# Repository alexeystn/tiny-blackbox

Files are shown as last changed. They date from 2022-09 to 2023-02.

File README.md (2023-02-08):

# Tiny Blackbox
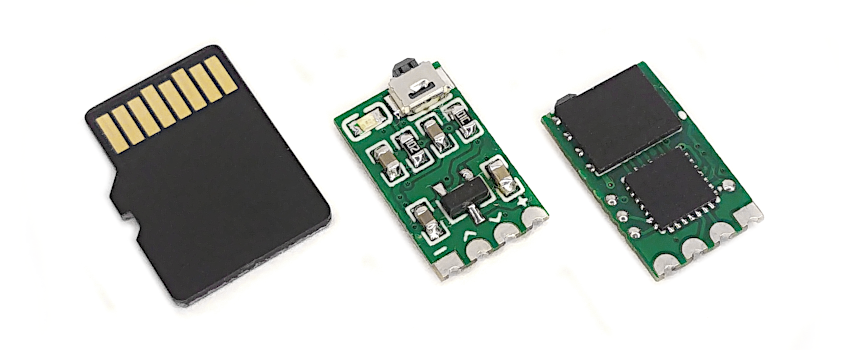
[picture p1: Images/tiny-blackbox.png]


Tiny Blackbox - open source ultra-light external logger for micro drones.<br>

* Size: 8 x 13 mm
* Weight: 0.32 g
* Logging rate: up to 8 kHz 
* Data rate: 1.5 Mbit/s
* Current consumption: < 30 mA
* Flash memory: 16 MB, W25Q128JVPIQ <br>
 &gt; 3 min at 4 kHz, full log <br>
 &gt; 45 min at 1 kHz, gyro-only log (all other fields disabled)
* MCU: STM32G031G8U6

For previous version with F042 chip go to [this page](https://github.com/alexeystn/tiny-blackbox/tree/stm32f042)

## Setup
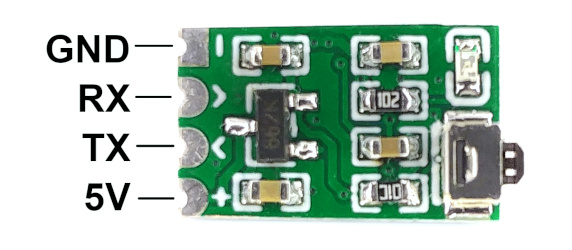
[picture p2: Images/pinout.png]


1) Connect the device to any free UART port on your flight controller (RX->TX, TX->RX).<br>
Signal wires must be tightly twisted to prevent interference.
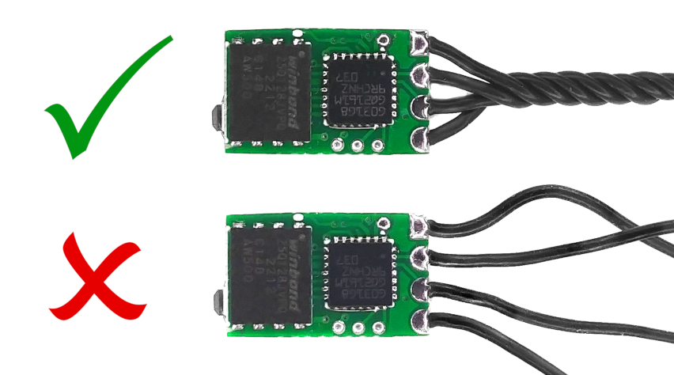
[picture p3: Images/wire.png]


2) Setup blackbox in Betaflight Configurator:
* Ports tab: Peripherals -> Blackbox logging, speed 1500000.
* Modes tab: Blackbox -> assign to any available AUX switch.
* Blackbox tab: Logging device -> Serial Port.
<details>
<summary><b>Screenshots</b></summary>
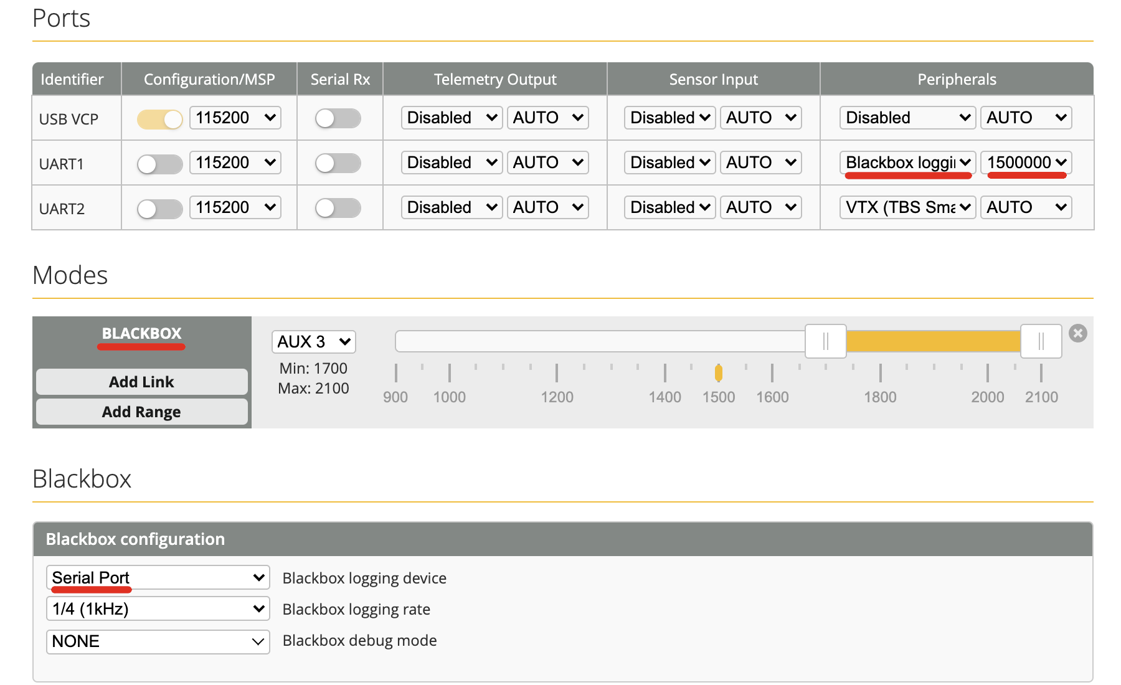
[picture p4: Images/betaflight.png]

</details>
<b>Warning!</b> Betaflight 4.3.1 has a bug in USB code, so logs might be corrupted when downloaded to PC. <br>
Please use Tiny Blackbox with Betaflight 4.4.x, 4.3.0, 4.3.2+ or 4.2.x.<br>
<br>

<b>Notice:</b> You can disable any blackbox fields in Betaflight when you don't need them. <br>
This will significantly reduce log size and eliminate lost frames. <br>
For example, `set blackbox_disable_pids = ON` or `set blackbox_disable_motors = ON`. <br>
Type `get blackbox_disable` in CLI to see all the available options.
<br>

## Operating modes
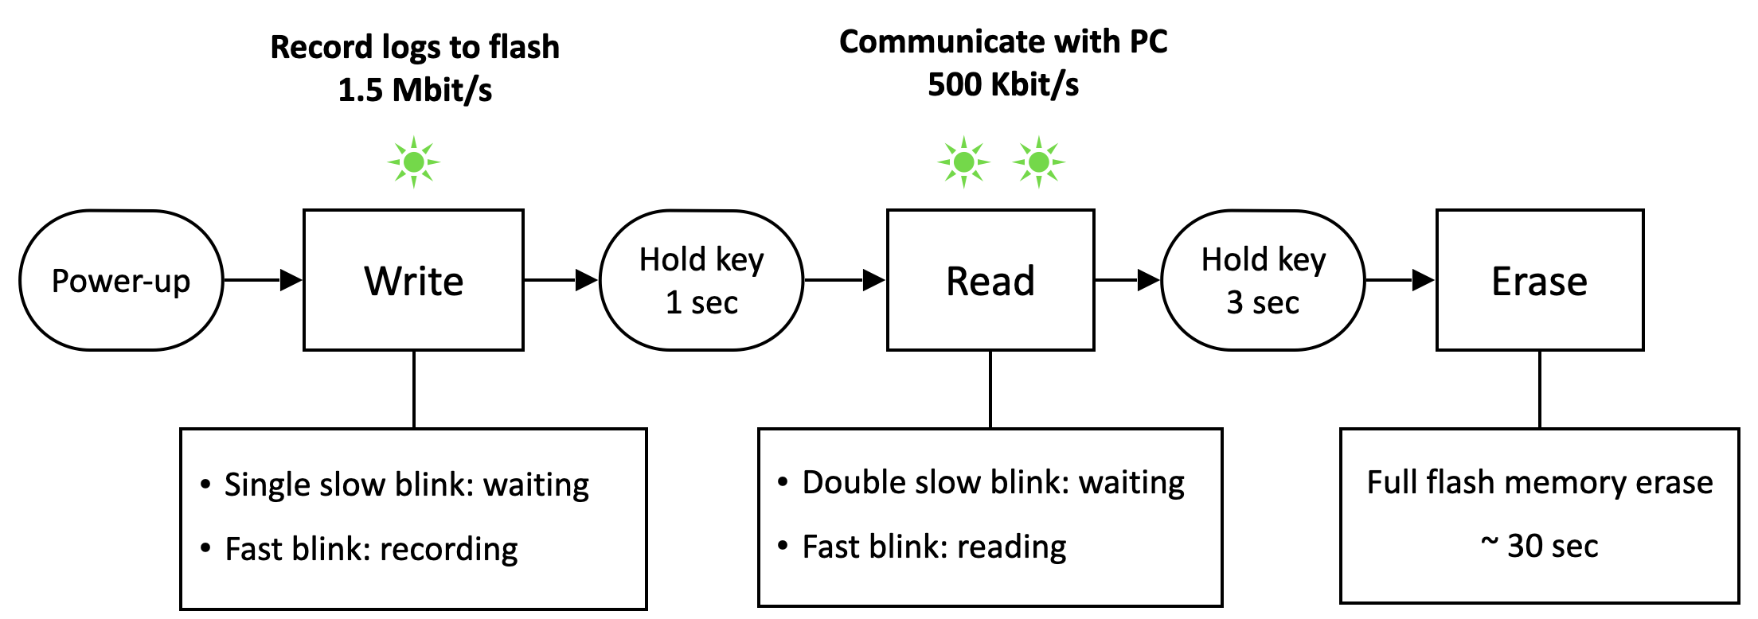
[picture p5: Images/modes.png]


## Read recorded logs
1) Download application on [Releases](https://github.com/alexeystn/tiny-blackbox/releases) page: "exe" for Windows, "app" for macOS.
2) Connect flight controller to PC.
3) Hold hardware button for 1 second to switch into Read mode (double blinks).
4) Open application, configure connection parameters and press "Connect".
5) Save logs to file and open them with Betaflight Blackbox Explorer.
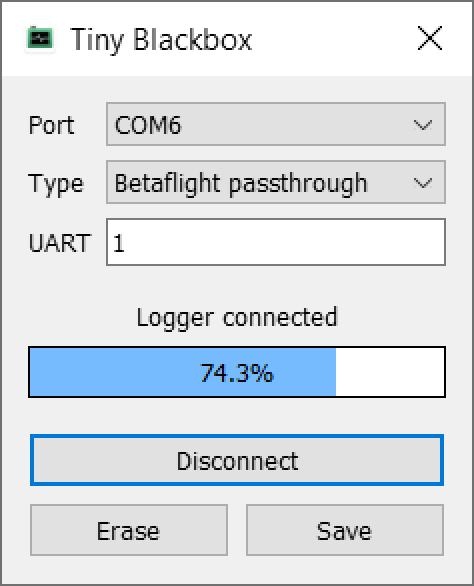
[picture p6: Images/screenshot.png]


Also, you can connect Logger directly to PC with FTDI/CP2102 adapter, without flight controller. <br>
Select "Serial-USB adapter" instead of "Betaflight passthrough".

<b>Notice:</b> Tiny-blackbox GUI may trigger antivirus alerts sometimes. This happens because binaries were built using "PyInstaller". You can add Tiny-blackbox executable to antivirus exception list or else run directly the source code.

<details>
<summary><b>Optional: Run the source code</b></summary>

1) Get the latest version of [Python](https://www.python.org/downloads/). <br>
Set "Add Python to PATH" checkbox while installing.
2) Install additional modules. <br>
Open "cmd.exe" (Windows) or "Terminal" (macOS) and enter: <br>
`pip3 install pyserial` <br>
`pip3 install PyQt5==5.15`
3) Download and run GUI Python script: [tinybb_gui.py](/Software/GUI/tinybb_gui.py).
</details>

<details>
<summary><b>Optional: Command line interface</b></summary>

CLI Python script for downloading logs is also available.<br>
Install Python and `pyserial` as described in section above.<br>
Run CLI script: [tinybb_cli.py](/Software/CLI/tinybb_cli.py)

</details>

## For developers and enthusiasts

* Use [EasyEDA](https://easyeda.com/editor) online editor to modify the board.
* PCB thickness 0.6 mm is optimum for weight/reliability.
* X5R/X7R capacitors are recommended.
* Edit and build firmware using [STM32CubeIDE](https://www.st.com/en/development-tools/stm32cubeide.html).
* Flash pre-built [HEX-firmware](/Firmware/Debug/Blackbox.hex) with [STM32CubeProgrammer](https://www.st.com/content/st_com/en/products/development-tools/software-development-tools/stm32-software-development-tools/stm32-programmers/stm32cubeprog.html) or [STLink](https://github.com/stlink-org/stlink) toolset.<br> 
Use following commands to flash with STLink tool:<br>
`st-flash erase`<br>
`st-flash --format ihex write "Blackbox.hex"`<br>
`st-flash reset`
* Connect ST-Link programmer to SWDIO and SWCLK pins:

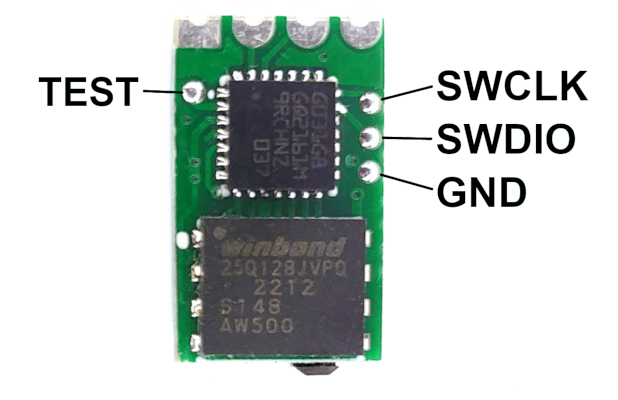
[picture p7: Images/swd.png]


## Contacts
 
Feel free to contact me in Telegram: [@AlexeyStn](https://t.me/AlexeyStn)

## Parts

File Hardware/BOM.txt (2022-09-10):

Designator   Value            Package
R1           1k               0603
R2           10k              0603
C1,C3        4.7uF            0603
C2,C4        100nF            0603
LD1          Green LED        0603
B1           B3U-3000P        1.2 × 3 × 2.5 mm
U1           XC6206P332MR     SOT-23-3
U2           STM32G031G8U6    UFQFPN-28, 4 × 4 mm
U3           W25Q128JVPIQ     WSON-8, 5 × 6 mm

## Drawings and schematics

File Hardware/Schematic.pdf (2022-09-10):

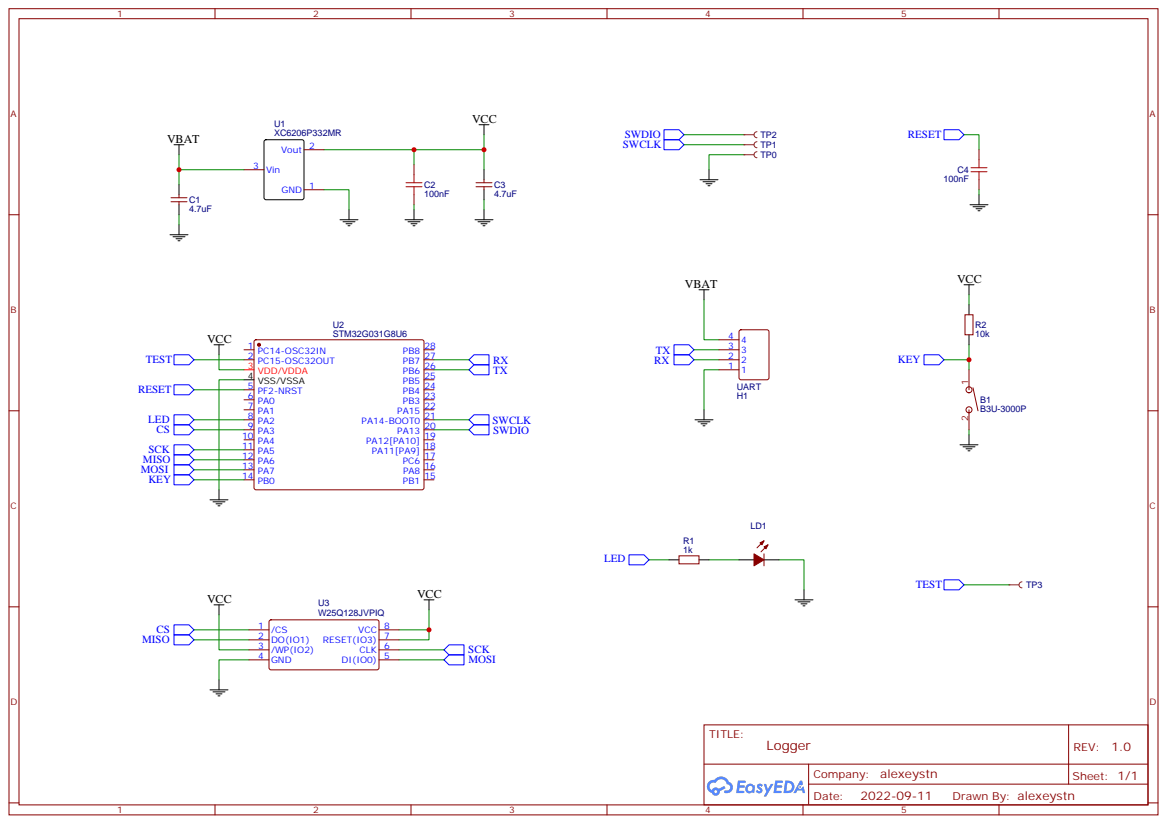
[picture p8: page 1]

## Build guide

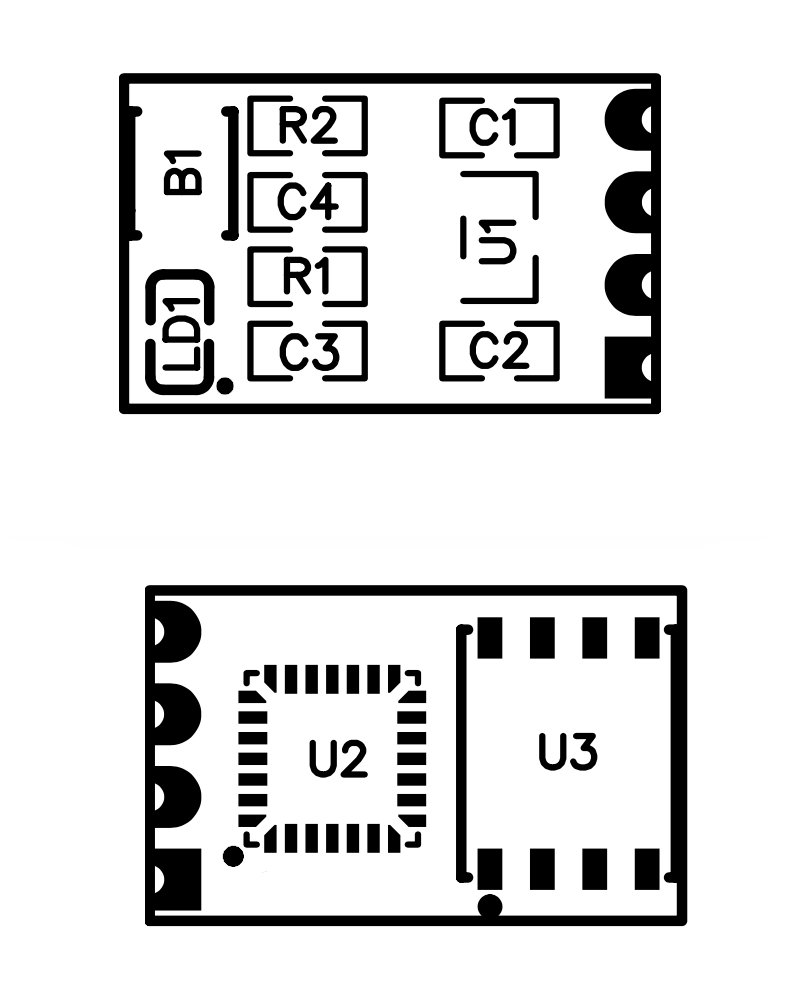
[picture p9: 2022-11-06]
Hardware/Assembly.png

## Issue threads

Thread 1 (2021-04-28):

samples to buy

WizzX-FPV, 2021-04-28:
Hallo, Thanks for really nice job.
Is there a place to order this as a finished PCB?

alexeystn, 2021-04-29:
Hi! Thank you!

The first small batch of loggers has been sold out already.
Unfortunately due to the global shortage of MCUs I cannot purchase any more chips for a reasonable price to produce more blackboxes. There are really serious issues with semiconductors supplies in the world now.

If one of FPV manufacturers starts producing these loggers, I will share a link here, of course. (I hope they will soon)

WizzX-FPV, 2021-04-30:
Thank and I'm looking forward to the link for a products!
Is there a way to use 32MB flash chip? (as Matek F722 miniSE has)

alexeystn, 2021-04-30:
Matek F722 mini SE has 32MB chip W25Q256JVEIQ in bigger package 8x6 mm,
Whereas my blackbox has a smaller 6x5 mm chip, same as Matek F722 mini (without SE), but it is only 16MB.
I have not found anything more than 16MB in such a small size.
Bigger chip requires some PCB modification, and most likely increasing PCB size.

mmstac, 2022-09-22:
Hi any changes to the supply situation? Is it possible to purchase this logger in 2022?

alexeystn, 2022-09-24:
Now I am migrating to G031G8U6 chips.
They are cheaper, widely available, and do not require crystal oscillators for logger.
First sample is already produced. It is being tested now.
As soon as I finish migration, new PCBs and firmware will be released.

trigger7, 2022-09-24:
Good news, thanks for your work !
If a batch of loggers is made, you can count me interested in buying one or two.

Username-unavailable1, 2024-01-05:
Is there any update or place to buy nowadays? The 2 places I look they are out of stock

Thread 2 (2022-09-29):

SD card size, and auto-write gyro when video's recording

CptCurk, 2022-09-29:
Hey,

I don't know anything about coding this kind of thing.

But you could use the tiny-blackbox, combined with the idea of yossato : https://github.com/yossato/virtualGimbal/ 3D printing an sd card size and linking the gyro with the micro SD card (on a normal SD card). Each time the SD is being recording on, the gyro records also.

I don't know how to manage battery, even if it's possible. But that would be the total killer stuff for so many peoples !

Best regards !

mituritsyn, 2022-09-29:
Isn't gyroflow better option?

CptCurk, 2022-09-29:
@mituritsyn what I mean, it's using the SD card idea with Gyroflow ! :)

alexeystn, 2022-10-03:
That's exactly what Gyroflow is doing.
I have no plans to build a combined gyro+logger device.
The aim of this project is creating the smallest general-purpose logger.
Although you can record gyro logs from external FC using Tiny-Blackbox.

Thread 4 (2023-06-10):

No logs

dzikus, 2023-06-10:
My own build is working with "Tiny_Blackbox" app. I can erase it via app (betaflight passtrough so serial connection is working with 500k baudrate acording to mode diagram) or thru button. But I cannot get any flight logs and usage is always 0.0%.

I configured UART1 as blackbox logging peripheral, also blackbox is serial port, 1/4 (800Hz as I'm using bmi270), GYRO_SCALED. Blackbox mode on aux4 and I see on OSD that it is working but no fast led flashing.

The rx/tx wires are twisted and as short as they can be. What else can I check?

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

dzikus, 2023-06-11:
I see some Python tests, I will try them with ftdi serial adapter.

alexeystn, 2023-06-13:
Did you arm your quad? Betaflight sends blackbox data to serial only when it's armed.
Is blackbox uart speed set to 1500000? (not 500000)

tchleb, 2023-07-12:
I can agree that the logging doesn't work with Betaflight 4.3 / 4.4
The last working Version is 4.2.11

With BF 4.3 /4.4 I can only read and erase the Blackbox over Betaflight Passthrough.

I tested on three different Targets and on all the behavior is the same.

For a quick Bench testing the blackbox on motor tab I can recommend to add:

set blackbox_mode = MOTOR_TEST

Logging starts when the motors test mode is active.

wKich, 2023-08-11:
Same issue here, but I use recommended buad rate. Bench testing doesn't work for me. Blackbox over Betaflight Passthrough works fine, erase and read. But no fast blinking on arm. I use BF4.5

alexeystn, 2023-08-11:
Sorry for delayed answer.
I have reproduced this issue and now I started investigating it. Hope to come up with the solution soon.

wKich, 2023-08-11:
@tchleb You can try 4.4.0. Logging works in that version. But it's weird why it doesn't on other versions

tchleb, 2023-08-11:
> @tchleb You can try 4.4.0. Logging works in that version. But it's weird why it doesn't on other versions

Already tried. I tested it with 4.4.0 and it didn't work reliably.

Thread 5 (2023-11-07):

SD Card Version？

L1cardo, 2023-11-07:
Hi, I found this project really interesting and I really love this project!
Are you planning to make an SD card version that we can use to log Gyro data for GyroFlow?
I know a little about PCBs and don't know much about coding, does your code work with bigger SD cards?

alexeystn, 2023-11-15:
Thank you!
1. You can use TinyBlackbox logs for GyroFlow, that is possible. It just requires more steps to prepare gyro logs.
2. I have no plans to make an SD card version, because there are already good SD loggers on market (OpenLager).
3. My code does not work with SD cards, but it can theoretically work with bigger flash chips. The issue is that other chips may have a large bulky package (which increase the weight and size of logger significantly), or rather too small (difficult to solder manually), or not widely available (rare and expensive).
Current 16 MBytes flash chip is a tradeoff choice.

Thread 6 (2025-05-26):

Is smaller possible?

Fourflies, 2025-05-26:
Hello Alexey, I was looking at your project and wondered if I could make it even smaller or lighter.  I found STM32L011F4U6 which is a 3x3 UFQFPN-20 package.  However, I'm not sure if it has enough flash, RAM, and timers for an easy port.

I also found W25Q256JWPIQ which is 32 MB in the same 5x6 package, but we would have to drop the circuit to 1.8 Volts. I believe the STM MCU can do it, but I'm not sure if 1.8 Volts is fine for the UART.

Finally I was thinking of changing the push switch to TS-1928-B, which is very small and light.

What do you think?  Thank you for your excellent project!

Fourflies, 2025-05-31:
Hi @alexeystn the spec sheets of the STM32F411CE and STM32F405RG seem to indicate that 1.8 Volts will be fine. I believe those two MCUs are very popular on tinywhoops, so probably dropping to 1.8 Volts on tiny-blackbox will be OK.

Fourflies, 2025-06-02:
@alexeystn Thank you for clarifying! I'll stick to the STM32G031G8U6 then. I'm going to attempt a build @ 1.8 V with the W25Q256JWPIQ flash chip and that tiny push switch, and I'll let you know how it goes. 🙂

Fourflies, 2025-07-19:
Hi @alexeystn, I have made my tiny-blackbox, and I just confirmed now that everything is working! Changes include:

* PCB shrunk to 8.0 x 10.6 mm.
* Weight down to 0.23 grams.
* Removed C4 and R2 (internal pull-up works).
* Changed to 0402 discrete components.
* Smaller 3.3 volt vreg.
* Smaller LED.
* Changed to TS-1928-B key switch.
* 32 MB flash

For now my flash is limited to 16 MB since I haven't added 32 MB support to the firmware yet. I believe I can do it and retain compatibility with 16 MB chips by implementing flash chip detection at boot time.

Will you be interested in incorporating all these changes into your repo and project?

alexeystn, 2025-08-03:
Hi @Fourflies

Thank you so much. I truly appreciate your work. You did a fantastic job!

I set the bitrate to 1.5 Mbps because it was sufficient for recording the full log at a 4 kHz PID loop frequency. Increasing the rate offers no real advantage and carries a higher risk of data corruption.

500 kbps for memory readout was chosen to ensure stable operation in passthrough mode. Using 1.5 Mbps leads to data losses in this case.

Unfortunately, I currently have very limited time and resources to continue maintaining and developing this project. Therefore, I suggest that you create your own fork of my repository and apply all your changes there. As for me, I’ll mention your repository and include a link to your advanced and improved blackbox version at the very beginning of my README.

Fourflies, 2025-08-03:
Hi @alexeystn, great to hear from you. Thanks for clarifying. For logging, when I experimented at 1.5 Mbps on the tiny-blackbox firmware I experienced data loss in my blackbox logs. The logs were still very readable, but the log analyser just reported some data loss. PID loop was also 4 kHz and logging rate was 1/2. I had to disable a number of logging fields in Betaflight to get a clean log. Not terrible, but I'm going to experiment with 2 Mbps in my firmware and see how it goes. What I do is default the baud rates to 1.5 Mbps and 500 kbps, and then there's a Read Mode command to change them, which gets written to a page at the end of the STM32 onboard flash. I've also added one more Key press state to reset back to defaults, in case someone sets a baud that kills Read Mode.

I've just started experimenting with Betaflight's passthrough mode and I see what you mean about 500 kbps. It seems to be limited to that speed for some reason. I might dig into BF code to try improve it, but I'm sticking to 500 kbps Read Mode for now in my blackbox.

Great, I will continue with my fork. Thanks. Currently my diff is about 5600 lines. I tried to figure out the license of your repo, but I wasn't sure. There's a GPLv3 license file, but the source files don't say much, or they assign copyright to STMicro. Do I need to worry about this? Do you care about the licensing?

Well, I'll update you here some more as I progress. Thank you for publishing such an awesome project! Are there any features or ideas you've had that you think will be good?

Fourflies, 2025-08-17:
Hey @alexeystn my suspicions about CPU resources seem to be correct. On this F411 flight controller I usually run a 108 MHz CPU clock. At 2 kHz logging rate, I can log 5 fields at 500 kbps baud rate. If I overclock to 120 MHz I'm able to increase that to 6 fields. At 1 kHz logging rate, I can log 10 fields at 500 kbps baud rate, and that increases to 12 fields at 120 MHz CPU clock.

I was surprised to see that only 500 kbps is needed for most logging situations. You only need a 2 kHz logging rate for troubleshooting noise, and for that you only need 5 fields of data. For PID tuning you need more fields, but then a 1 kHz logging rate is enough. I think increasing baud to 1000 kbps would allow all 14 fields at 2 kHz logging rate, if there are enough CPU resources. Unfortunately my FC doesn't have enough sensors to test with all 14 fields, but through extrapolation I believe 1000 kbps is the highest baud rate you'd ever need, at least as of Betaflight 4.5.2.

The main downside with these low baud rates is that Betaflight's graphical port configurator does not display them in its pull-down menus. They have to be configured with the CLI. At some point I'll try get this fixed in the BF project.

Just a small update from my testing. Warm wishes! Oh, please let me know about my licensing questions?

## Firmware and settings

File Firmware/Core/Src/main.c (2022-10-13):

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
/* Includes ------------------------------------------------------------------*/
#include "main.h"

/* USER CODE BEGIN Includes */
#include "w25q.h"
#include "logger.h"
#include "led.h"
#include "cli.h"
/* USER CODE END Includes */

SPI_HandleTypeDef hspi1;
DMA_HandleTypeDef hdma_spi1_rx;
DMA_HandleTypeDef hdma_spi1_tx;

TIM_HandleTypeDef htim16;
TIM_HandleTypeDef htim17;

UART_HandleTypeDef huart1;
DMA_HandleTypeDef hdma_usart1_rx;

void SystemClock_Config(void);
static void MX_GPIO_Init(void);
static void MX_SPI1_Init(void);
static void MX_DMA_Init(void);
static void MX_USART1_UART_Init(void);
static void MX_TIM17_Init(void);
static void MX_TIM16_Init(void);
/**
  * @brief  The application entry point.
  * @retval int
  */
int main(void)
{
  /* USER CODE BEGIN 1 */
  enum status_t status;
  /* USER CODE END 1 */

  /* MCU Configuration--------------------------------------------------------*/

  /* Reset of all peripherals, Initializes the Flash interface and the Systick. */
  HAL_Init();

  /* Configure the system clock */
  SystemClock_Config();

  /* USER CODE BEGIN SysInit */

  // IMPORTANT!!!
  // MX_DMA_Init() must be called before MX_SPI1_Init()
  // CubeMX generate DMA after SPI init which causes
  MX_DMA_Init();
  #define MX_DMA_Init()  while (0) {};

  /* USER CODE END SysInit */

  /* Initialize all configured peripherals */
  MX_GPIO_Init();
  MX_SPI1_Init();
  MX_DMA_Init();
  MX_USART1_UART_Init();
  MX_TIM17_Init();
  MX_TIM16_Init();
  /* USER CODE BEGIN 2 */

  #undef MX_DMA_Init // End of workaround

  W25_ReadID();
  Logger_Init();
  LED_Init();
  LED_SetStatus(STATUS_IDLE_WRITE);

  while (1) { // WRITE loop

    status = Logger_WriteLoop();
    if (Logger_IsMemoryFull()) {
      status = STATUS_FULL;
    }
    if (Logger_IsFifoOverflow()) {
      status = STATUS_ERROR;
    }
    LED_SetStatus(status);

    if (isKeyPressed(1000)) {
      break;
    }
  }

  Logger_Stop();
  LED_SetStatus(STATUS_IDLE_READ);
  LED_Blink(3);
  while (!isKeyUnpressed(200)) {};
  CLI_Start();

  while (1) { // READ loop

    enum cli_cmd_t cmd;
    if (CLI_GetCommand(&cmd)) {
      LED_SetStatus(STATUS_BUSY);

      switch (cmd) {
      case CMD_READ:
        Logger_Read(0);
        break;
      case CMD_DUMP:
        Logger_Read(1);
        break;
      case CMD_ERASE:
        Logger_Erase();
        break;
      case CMD_INFO:
        Logger_SendInfo();
        break;
      case CMD_TEST:
        Logger_SelfTest();
        break;
      default:
        break;
      }
      LED_SetStatus(STATUS_IDLE_READ);
    }

    if (isKeyPressed(3000)) {
      break;
    }
  }

  LED_SetStatus(STATUS_BUSY);
  Logger_Erase();
  NVIC_SystemReset();

  /* USER CODE END 2 */

  /* Infinite loop */
  /* USER CODE BEGIN WHILE */
  while (1)
  {
    /* USER CODE END WHILE */

    /* USER CODE BEGIN 3 */
  }
  /* USER CODE END 3 */
}

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


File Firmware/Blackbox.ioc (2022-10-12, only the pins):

Mcu.UserName=STM32G031G8Ux
PA13.Signal=SYS_SWDIO
PA14-BOOT0.Signal=SYS_SWCLK
PA2.GPIO_Label=LED
PA2.Signal=GPIO_Output
PA3.GPIO_Label=SPI1_NSS
PA3.Signal=GPIO_Output
PA5.Signal=SPI1_SCK
PA6.Signal=SPI1_MISO
PA7.Signal=SPI1_MOSI
PB0.GPIO_Label=KEY
PB0.Signal=GPIO_Input
PB6.Signal=USART1_TX
PB7.Signal=USART1_RX

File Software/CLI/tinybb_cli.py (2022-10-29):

import sys
import time
import json
from datetime import datetime
import serial
import serial.tools.list_ports


def get_default_config():
    print('Loading default config')
    default_config = {"port": "COM0", "use_passthrough": 0, "bf_uart_number": 1}
    save_config(default_config)
    return default_config


def load_config():
    try:
        with open('config.json', 'r') as f:
            config = json.load(f)
    except FileNotFoundError:
        print('File "config.json" not found')
        config = get_default_config()
        print('Check settings in "config.json"')

    except json.JSONDecodeError:
        print('File "config.json" is corrupted')
        print('Would you like to reset settings? [Y/n]')
        user_input = input()
        if user_input.upper() == 'Y':
            config = get_default_config()
        else:
            sys.exit(0)

    available_ports = [c.device for c in serial.tools.list_ports.comports()]
    if not config['port'] in available_ports:
        print('Cannot find serial port "{0}"'.format(config['port']))
        print('Select one of the available ports:')
        for i, port in enumerate(available_ports):
            print('{0}: {1}'.format(i+1, port))
        print('>> ', end='')
        n = int(input())
        config['port'] = available_ports[n-1]
    return config


def save_config(config):
    with open('config.json', 'w') as f:
        json.dump(config, f, indent=2)


def bf_enable_passthrough(ser, config):
    print()
    print('===== Betaflight CLI mode =====')
    ser.write(b'#\n')
    ser.readline()
    request_str = 'serialpassthrough ' + str(config['bf_uart_number'] - 1) + ' 500000\n'
    ser.write(request_str.encode())
    while True:
        res = ser.readline()
        if len(res) == 0:
            break
        s = res.decode().strip()
        if len(s) > 0:
            print(' >> ' + s)
    print('===============================')
    print()
    time.sleep(1)


def save_rx_data_to_file(ser):
    rx_counter = 0
    rx_counter_scaled_prev = 0
    filename = 'Blackbox_Log_' + datetime.now().strftime('%Y%m%d_%H%M%S.bbl')
    f = open(filename, 'wb')
    print('Downloading {0}:'.format(filename))
    print('Press Ctrl+C to stop')
    try:
        while True:  # print dots and megabytes
            d = ser.read(1000)
            if len(d) > 0:
                rx_counter += len(d)
                f.write(d)
                rx_counter_scaled = rx_counter // (2**15)
                if rx_counter_scaled > rx_counter_scaled_prev:
                    print('.', end='', flush=True)
                    f.flush()
                    if rx_counter_scaled % 32 == 0:
                        print(' {0:.0f} Mb'.format(rx_counter/(2**20)))
                rx_counter_scaled_prev = rx_counter_scaled
            else:
                break
    except KeyboardInterrupt:
        print()
        print('cancelled')
    f.close()
    print('\n'+str(rx_counter) + ' bytes received')
    print(f.name + ' saved')


def process_args():
    arguments = sys.argv
    if len(arguments) > 1:
        a = arguments[1]  # skip [0] .py script name
        if (len(a) == 2) and (a.startswith('-')):
            return a[1]  # remove dash
    else:
        return None


def func_information(ser):
    ser.flushInput()
    ser.write('\n'.encode())
    time.sleep(0.1)
    ser.write('info\n'.encode())
    resp = ser.readline()
    if len(resp) > 0:
        print(resp.decode().strip())
    else:
        print('No response from Blackbox')
        print('Check if Read mode is ON')


def func_read(ser):
    ser.write('read\n'.encode())
    save_rx_data_to_file(ser)


def func_dump(ser):
    ser.write('dump\n'.encode())
    save_rx_data_to_file(ser)


def wait(ser):
    counter = 0
    need_newline = True
    while True:
        res = ser.readline()
        if len(res) == 0:
            break
        else:
            res = res.decode().strip()
            if len(res) == 1:  # heartbeat signal
                print(res, end='', flush=True)
                counter += 1
                if counter % 32 == 0:
                    print()
            else:
                if need_newline:
                    print()
                    need_newline = False
                print(res)
            if res == 'Done':
                break


def func_erase(ser):
    print('Erasing, wait ~40 seconds')
    ser.write('erase\n'.encode())
    wait(ser)


def func_test(ser):
    print('Self-testing, wait ~3 min')
    ser.write('test\n'.encode())
    wait(ser)


def func_exit(ser):
    _ = ser
    return


def main():
    config = load_config()
    commands = dict({'i': ['Information', func_information],
                     'r': ['Read memory', func_read],
                     'd': ['Dump full memory', func_dump],
                     'e': ['Erase', func_erase],
                     't': ['Self-test', func_test],
                     'x': ['Exit', func_exit]})
    cli_argument = process_args()
    if cli_argument and cli_argument not in commands:
        print('Wrong command line argument')
        sys.exit()

    ser = None
    try:
        ser = serial.Serial(config['port'], 500000, timeout=1)
        print('Open ' + config['port'] + ' successfully')
        save_config(config)
        if config['use_passthrough'] != 0:
            bf_enable_passthrough(ser, config)
        func_information(ser)
        if cli_argument:
            commands[cli_argument][1](ser)
        else:
            for k in commands:
                print(' ' + k + ' - ' + commands[k][0])
            print('Enter command: ')
            while True:
                user_command = None
                while user_command not in commands:
                    print('>> ', end='')
                    user_command = input()
                commands[user_command][1](ser)
                if user_command == 'x':
                    break
    except serial.SerialException:
        print('Cannot open ' + config['port'])
    except Exception as e:
        print(e)
    finally:
        ser.close()
        print()


if __name__ == "__main__":
    main()

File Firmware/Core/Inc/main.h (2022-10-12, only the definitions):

#define TEST_POINT_Pin GPIO_PIN_15
#define TEST_POINT_GPIO_Port GPIOC
#define LED_Pin GPIO_PIN_2
#define LED_GPIO_Port GPIOA
#define SPI1_NSS_Pin GPIO_PIN_3
#define SPI1_NSS_GPIO_Port GPIOA
#define KEY_Pin GPIO_PIN_0
#define KEY_GPIO_Port GPIOB

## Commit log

2021-01-10 Add key and led logic
2021-01-11 Add SPI read with DMA
2021-01-12 Add LED blinking modes
2021-01-14 Fix memory size form 64 to 128
    [logger.c, main.c, w25q.c]
2021-01-14 Low level LED while button pressed
2021-01-14 Simplified button command logic
2021-01-19 Update schematic
2021-01-19 Add Bill of Materials
2021-01-29 Fix Erasing status LED
    [main.c]
2021-01-29 Choose any available ST-Link device
2021-02-22 Change Uart ID
2022-09-07 Disable UART TX interrupt
2022-09-08 Re-enable USART RX interrupt
2022-09-09 Use circular UART DMA mode
2022-09-10 Update hardware files
    [Drill_PTH_Through.DRL, Gerber_BoardOutline.GKO, Gerber_BoardOutlineLayer.GKO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]
2022-09-10 Display 'no errors' message
    [test_sequence_verify.py]
2022-09-10 Add Debug pin macro definitions
2022-09-10 Workaround for SPI DMA initialization
    [main.c]
2022-09-10 Fix bug: >100% memory full
    [logger.c]
2022-10-10 Print remeining erase time
2022-10-11 Remove outdated hardware/firmware
    [Gerber_BoardOutline.GKO, Gerber_BottomLayer.GBL, Gerber_BottomSolderMaskLayer.GBS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]
2022-10-12 One-second calibration pulses on Test Pin
2022-10-13 Handle FIFO overflow error
    [led.c, logger.c, main.c]
2022-10-17 Send joint packets
2022-10-29 Show error when connection is lost
    [tinybb_gui.py]
2022-11-13 Add wiring image
2023-01-17 Fix config load on Linux
    [tinybb_gui.py]

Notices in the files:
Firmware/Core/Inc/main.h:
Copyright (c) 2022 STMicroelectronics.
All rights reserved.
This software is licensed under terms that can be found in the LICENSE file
